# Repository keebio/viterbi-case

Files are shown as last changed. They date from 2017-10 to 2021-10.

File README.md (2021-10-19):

# Viterbi Keyboard Case

Here's case design files for the [Viterbi](https://keeb.io/products/viterbi-keyboard-pcbs-5x7-70-split-ortholinear).

## Case pieces in `old` folder

- Switch layer (`viterbi-switch.svg`)
- Bottom layer (`viterbi-bottom.svg`) *included .stl and .sldprt in 12mm for easier 3D printing*
- Middle layer (`viterbi-middle.svg`)

The exterior plate dimensions of these files are 145.55mm x 107.45mm.
## Case pieces in `rev2` folder

The top shell and mid layer STL case pieces in here are for an enclosed case that surrounds the switch and bottom plates. They use 20mm M2 screws inserted through the bottom plate and screws into the top shell.

## Screws and Standoffs

This case was designed to use M2 screws and standoffs. The holes in the middle layers are for the standoffs, while the holes in the top and bottom layers are only wide enough for the screws. M2 screws and standoffs that fit the case can be purchased at Keebio: [M2 Screws & Standoffs](https://keeb.io/products/m2-screws-and-standoffs)

## Fabrication

### Sculpteo

[Sculpteo](https://www.sculpteo.com) offers laser cutting services and is relatively easy to use.

Steps:
- Upload file
- Scale the object correctly, using the dimensions of the plates
- Make sure all colors are set to "Cut" and not any of the engraving choices
- Select your material and order

### Ponoko

To have the case made with Ponoko, you can't take these files as is and send them off to them. First, you'll need to download the templates for P1, P2, & P3 sheets from here, depending on what vector editor you are using:

- [Inkscape templates](https://www.ponoko.com/starter-kits/inkscape)
- [Adobe Illustrator template](https://www.ponoko.com/starter-kits/adobe-illustrator)
- [Other](https://www.ponoko.com/make-and-sell/design-it-yourself)

Next, open up the template of the sheet size you want and open up the case design files as well. Then, copy the drawings in the case design files into the template. Remove any overlapping lines to reduce the cutting cost using this guide: [Avoid doubled up lines](http://support.ponoko.com/hc/en-us/articles/220289608-Avoid-doubled-up-blue-cutting-lines-in-your-designs).

### Middle Layer Thickness

If you're having the middle layers made, from the top of the switch plate to the top of the bottom plate, the minimium distance between the two required is 12mm if the plastic on the header pins is removed. The requirement is slightly more (about 13.5mm) if you leave the plastic on. Therefore, the following middle layer thickness are needed based on the thickness of the switch layer:

- 1.5mm Stainless steel switch plate: 10.5mm
    - Usually accomplished with:
        - 2x4.5mm + 1x1.5mm layers
        - or 3x3mm + 1x1.5mm layers
        - or 4x3mm layers
- 3mm acrylic switch plate: 9mm
    - Usually accomplished with:
        - 2x4.5mm layers
        - or 3x3mm layers

## License

These case files are released under the MIT License.

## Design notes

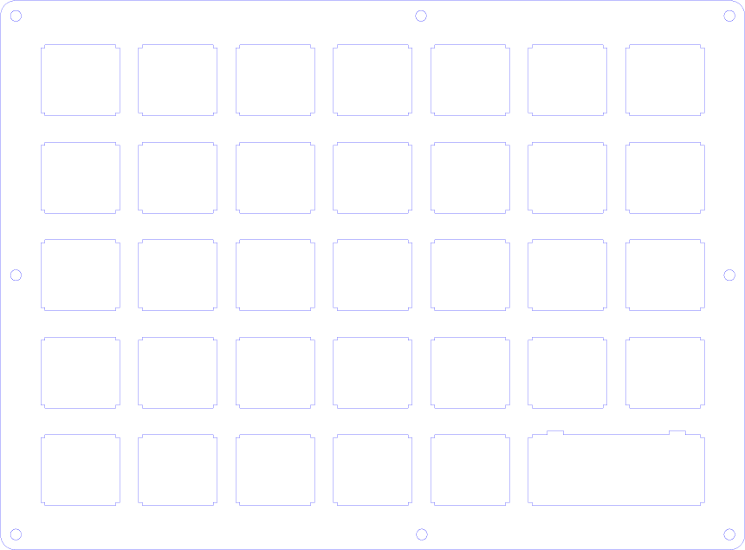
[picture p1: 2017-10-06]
images/viterbi-switch.png

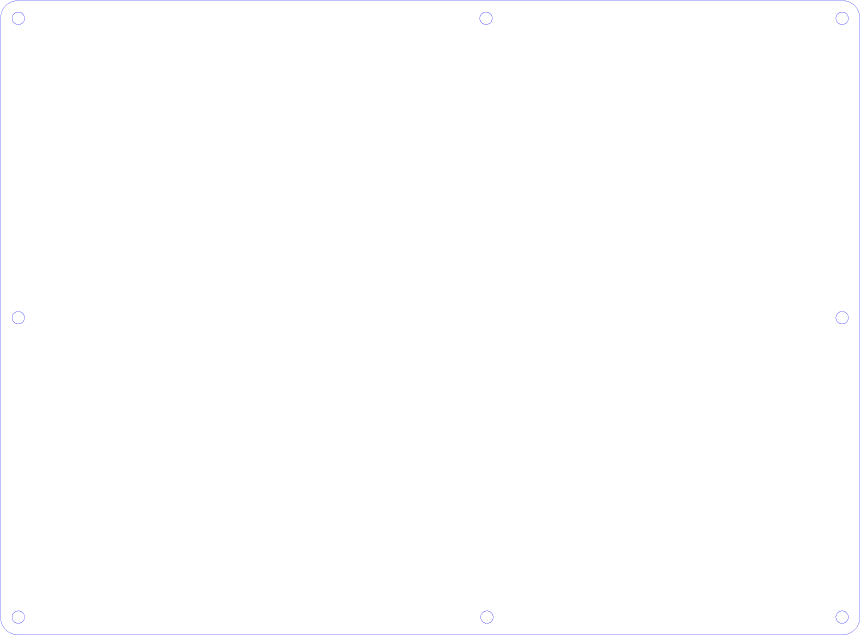
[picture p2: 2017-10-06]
images/viterbi-bottom.png

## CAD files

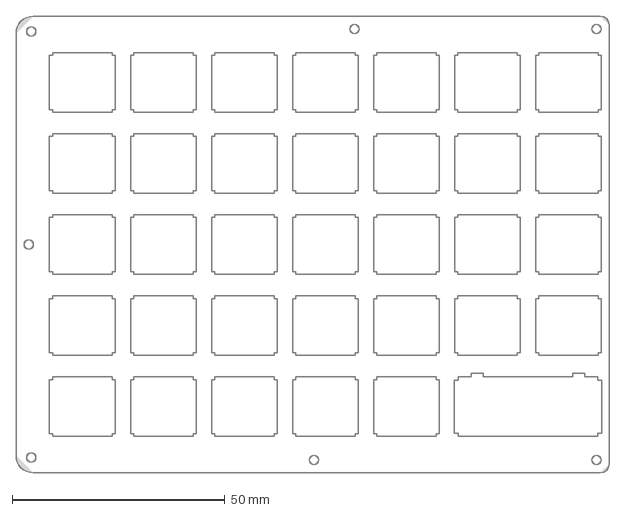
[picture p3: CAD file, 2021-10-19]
rev2/Viterbi Switch Plate.dxf
139.5 x 107.4 mm

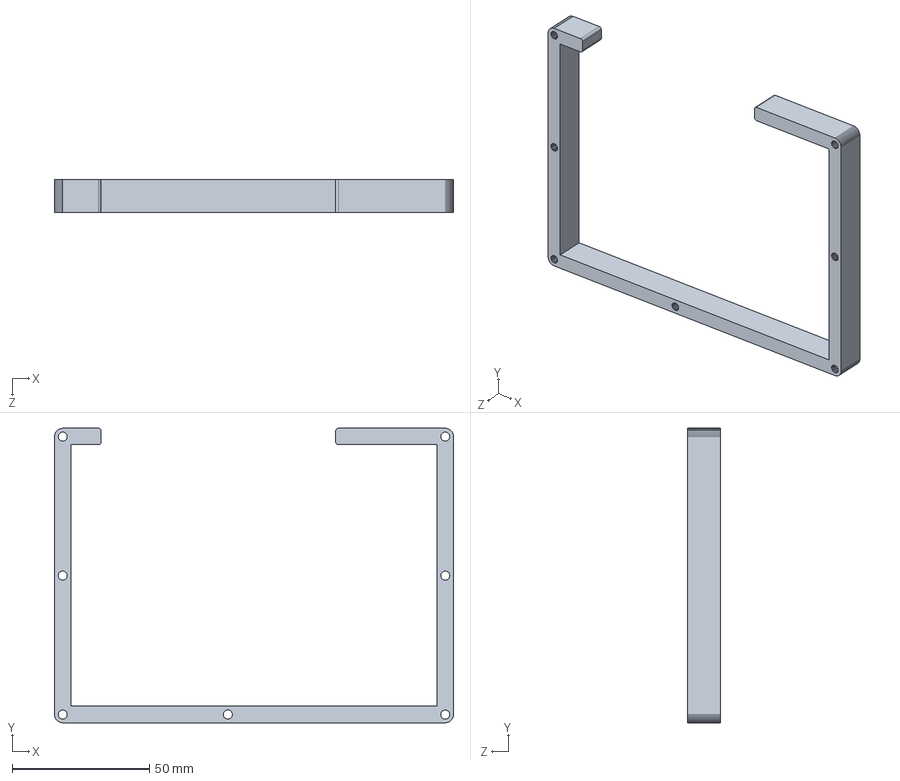
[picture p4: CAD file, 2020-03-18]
viterbi-middle.SLDPRT
145.5 x 107.5 x 12.0 mm

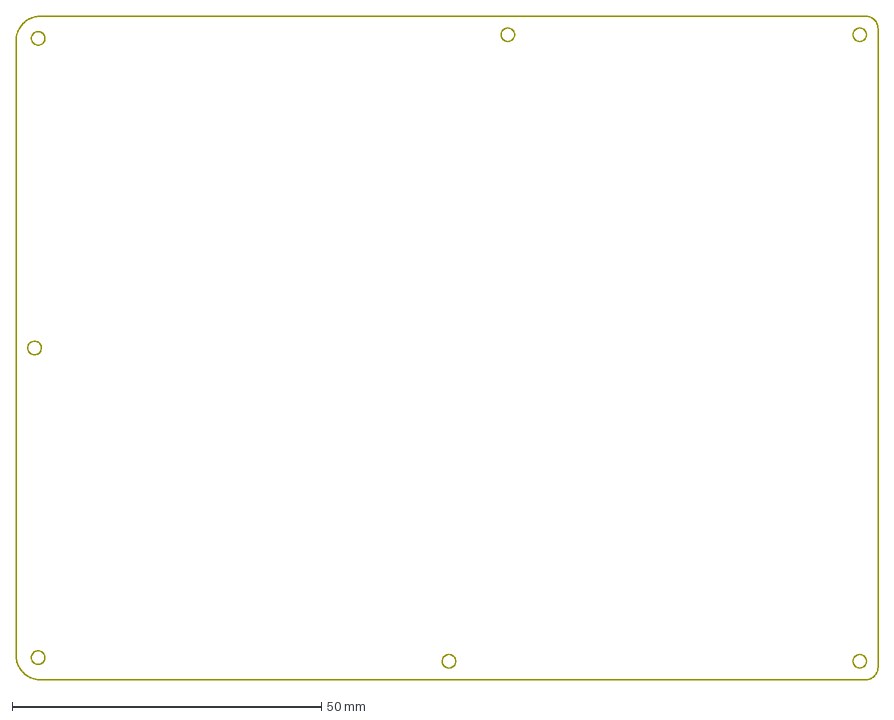
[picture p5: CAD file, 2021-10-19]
rev2/Viterbi Bottom Plate.dxf
139.5 x 107.4 mm

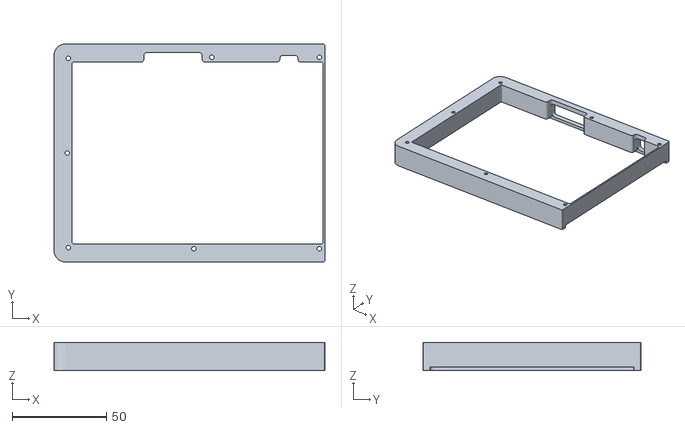
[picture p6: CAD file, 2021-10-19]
rev2/Viterbi Mid Layer.stl
143.5 x 115.4 x 15.0

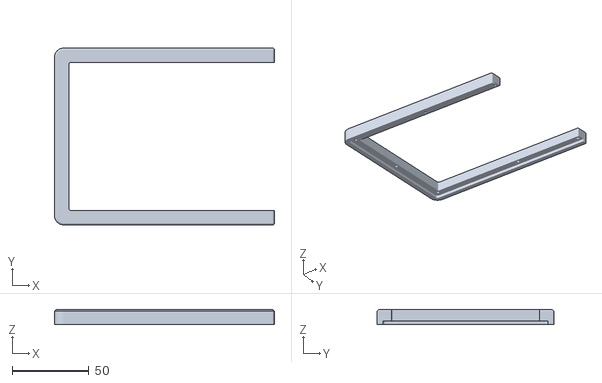
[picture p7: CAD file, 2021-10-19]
rev2/Viterbi Top Shell.stl
143.5 x 115.4 x 9.50

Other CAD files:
old/viterbi-middle.STL
old/viterbi-middle.dxf
viterbi-middle.STL
viterbi-middle.dxf

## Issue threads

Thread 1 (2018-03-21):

Any plans to add files for a switch layer that supports 1.25u modifiers?

pandaburn, 2018-03-21:
I'm interested in this keyboard because of the potential for an ortho with larger modifier keys. Would be great to be able to get a custom case for it.

nooges, 2021-10-19:
Option for 1.25u mods went away with Rev. 2.

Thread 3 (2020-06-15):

Rev 2 case files

tott, 2020-06-15:
Will these case files work for the Rev 2 PCB and if not, are there any plans for an updated version and when can it be expected?

carlosrfernandez, 2020-10-11:
I had a friend print the middle layer case for the rev2 and it doesn't fit the plates.

I'm not very familiar with 3D printing, but I don't think the models for revision 1 will work on Rev2.

It would be cool if they were made available...

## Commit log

2017-10-06 Add images of plates
2019-02-16 Added files for easier 3D printing
    Converted .ai file to a .dxf and then turned into a 3D model .stl file at 12mm height. Also including .sldprt for use with CAD software as well.
    [middle.SLDPRT, middle.STL, viterbi-middle.dxf]
2019-02-16 Added files for easier 3D printing
    Middle layer in 12mm
    [viterbi-middle.STL]
2019-02-16 Removed poorly named file
    [middle.STL]
2019-02-16 Added files for easier 3D printing
    [viterbi-middle.SLDPRT]
2021-10-19 Move files to legacy directory
    [viterbi-middle.SLDPRT, viterbi-middle.STL, viterbi-middle.dxf]
2021-10-19 Add Rev. 2 3D print files
    [Viterbi Mid Layer.stl, Viterbi Top Shell.stl]
2021-10-19 Add plate files
    [Viterbi Bottom Plate.dxf, Viterbi Switch Plate.dxf]
